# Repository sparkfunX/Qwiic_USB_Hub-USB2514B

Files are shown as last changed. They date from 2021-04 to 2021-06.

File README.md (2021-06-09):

SparkFun Qwiic USB Hub - USB2514B
========================================

SparkX USB Hub - USB2514B (Qwiic) (https://www.sparkfun.com/products/18014)

[*SparkX USB Hub - USB2514B (Qwiic) (SPX-18014)*](https://www.sparkfun.com/products/18014)

There are times when you have multiple USB devices in your prototype or device and you just want to plug in one cable. You need a built in USB hub! 

The [Qwiic USB Hub](https://www.sparkfun.com/products/18014) is a simple breakout board for the USB2514B USB hub IC. What gives it extra flair is the ability to configure the device over I2C. Out of the box, the board will appear as a standard USB 2.0 Hub; no configuration necessary. Closing the I2C jumper will put the device into configuration mode. We've got an Arduino Library to help you set the various parameters of the hub including VID/PID, downstream max current, even language ID and product names. 

Note: Once the configuration bytes are set and the USB2514B is told to 'attach' it will enumerate as a HUB and the configuration cannot be changed until the IC is reset. 

The USB2514 is a 4-port 2.0 USB hub. Who cares about USB 2.0 these days? The vast majority of projects we work on have a simple USB-to-Serial IC on it that do not require gigabit datarates. The USB251xB is a simple hub IC allowing multiple USB things to live under one USB connection; this is especially useful when prototyping a new product where you want the user to plug in just one cable.

SparkFun labored with love to create this code. Feel like supporting open source hardware? 
Buy a [board](https://www.sparkfun.com/products/18014) from SparkFun!

Repository Contents
-------------------

* **/hardware** - Eagle files
* **/documents** - Datasheets and other source documents

Documentation
--------------

* **[Arduino Library](https://github.com/sparkfun/SparkFun_USB251x_Arduino_Library)** - Main repository (including hardware files)
* **[Installing an Arduino Library Guide](https://learn.sparkfun.com/tutorials/installing-an-arduino-library)** - Basic information on how to install an Arduino library.

Products that use this Repository
--------------

* [SPX-18014](https://www.sparkfun.com/products/18014)

License Information
-------------------

This product is _**open source**_! 

Please review the LICENSE.md file for license information. 

If you have any questions or concerns on licensing, please contact technical support on our [SparkFun forums](https://forum.sparkfun.com/viewforum.php?f=152).

Distributed as-is; no warranty is given.

- Your friends at SparkFun.

_<COLLABORATION CREDIT>_

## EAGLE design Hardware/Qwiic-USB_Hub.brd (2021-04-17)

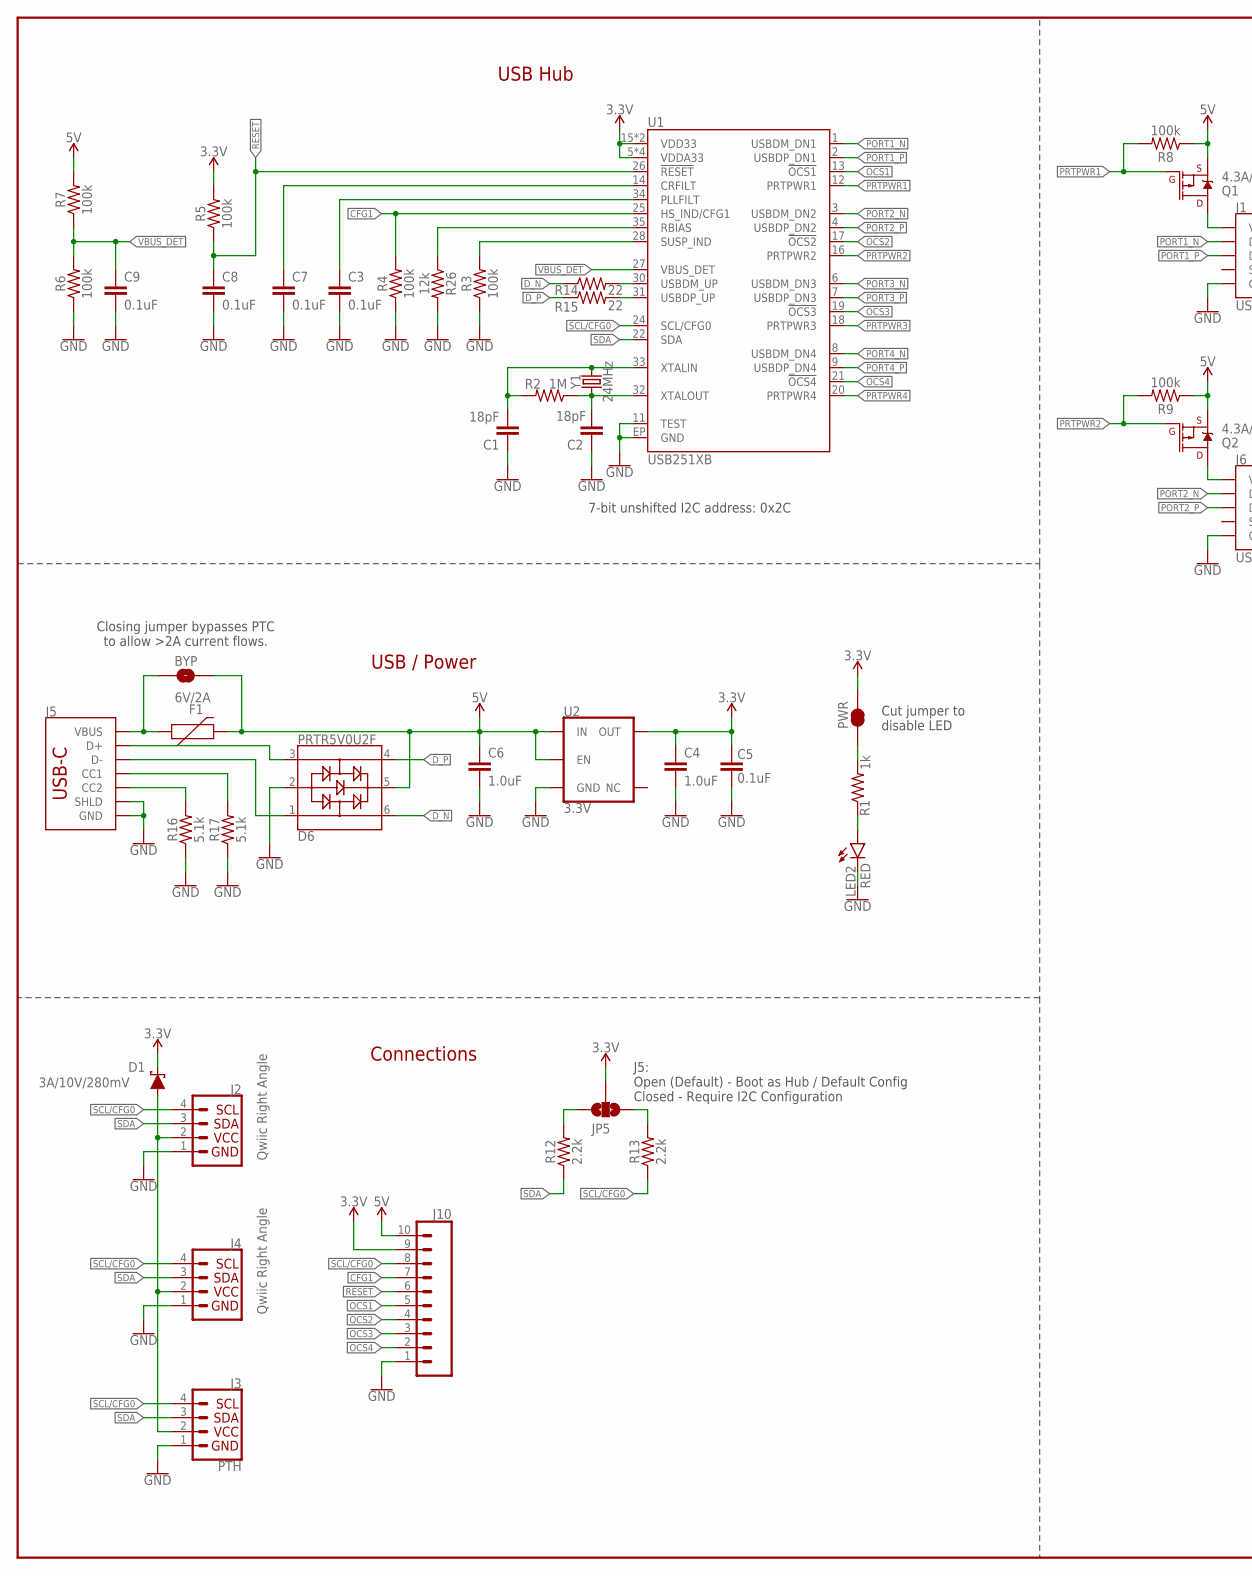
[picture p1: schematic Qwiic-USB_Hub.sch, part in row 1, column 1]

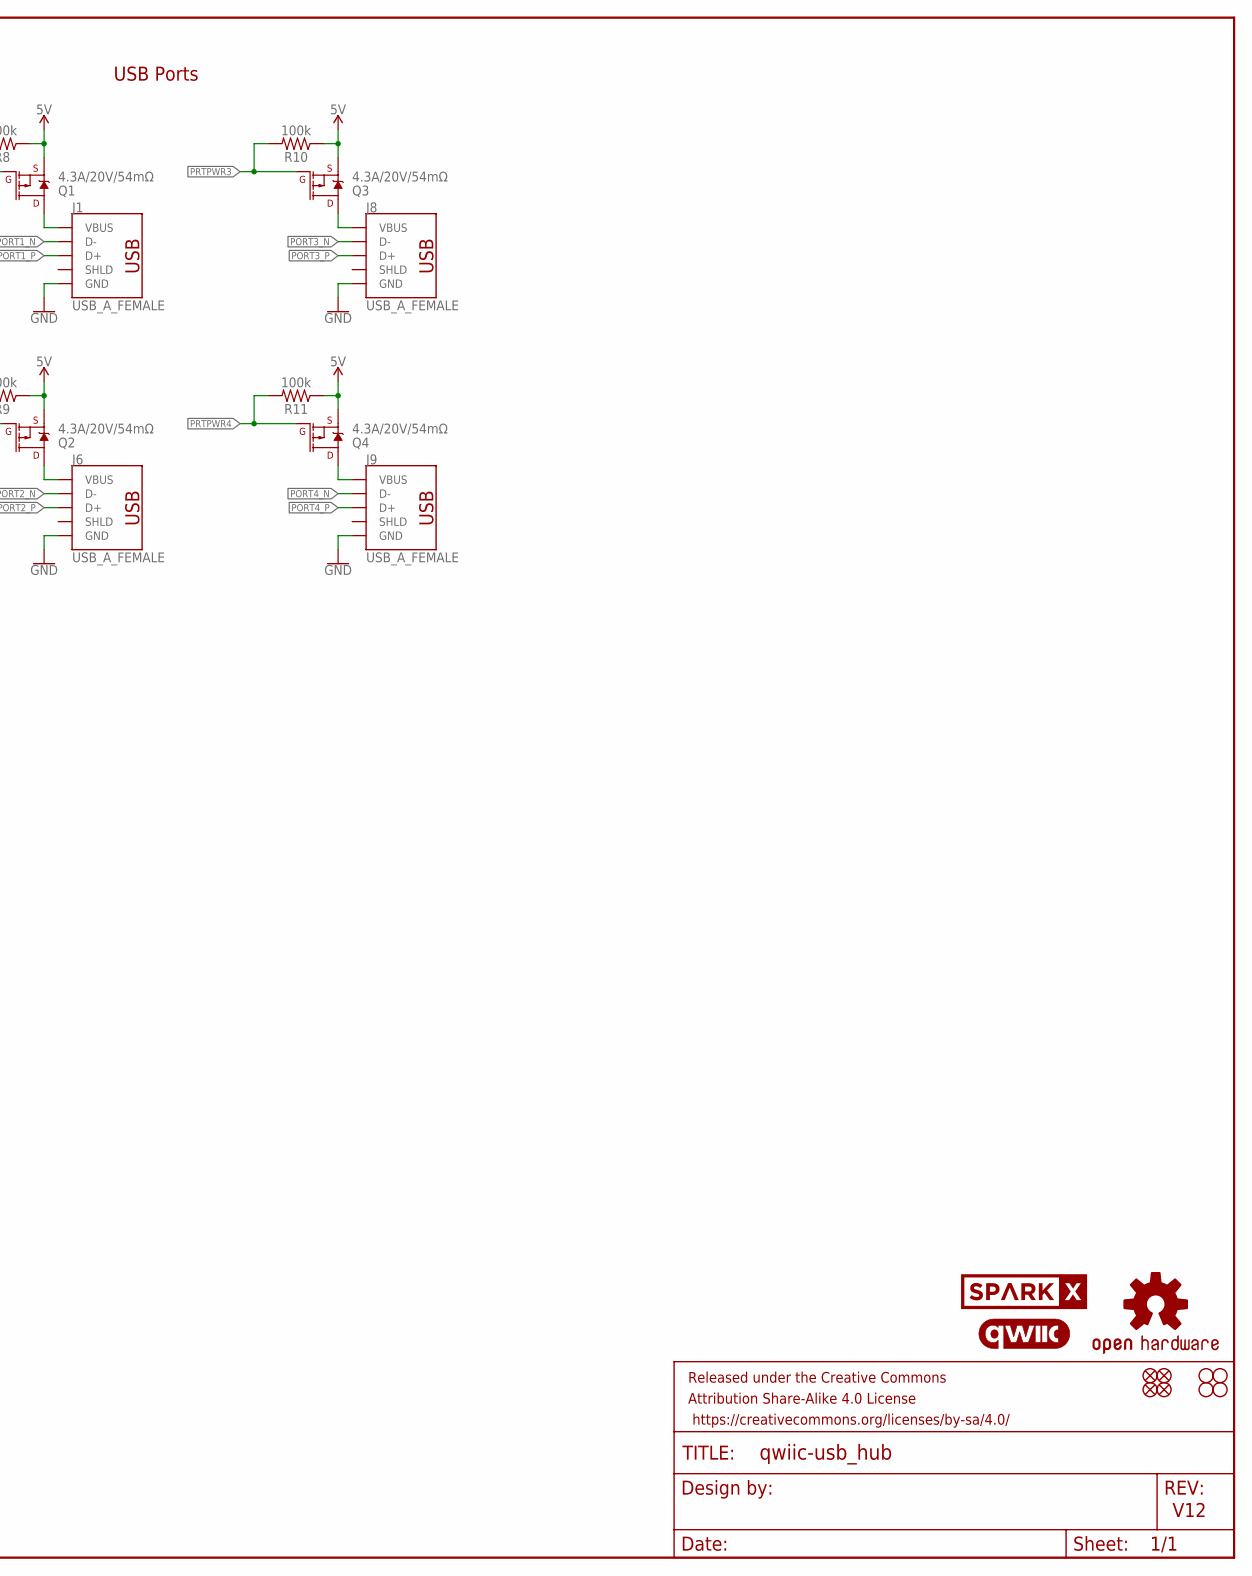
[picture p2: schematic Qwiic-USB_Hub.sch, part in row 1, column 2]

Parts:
BYP: JUMPER-SMT_2_NO_SILK; SMT-JUMPER_2_NO_SILK
C1, C2: 18pF; 0603
C3, C5, C7, C8, C9: 0.1uF; 0603
C4, C6: 1.0uF; 0603
D1: 3A/10V/280mV; SOD-323
D6: PRTR5V0U2F; SOT886
F1: 6V/2A; 1210
FRAME2: FRAME-LEDGER; CREATIVE_COMMONS
J1, J6, J8, J9: USB_A_FEMALE; USB-A-S-NOSILK-FEMALE
J2, J4: Qwiic Right Angle; JST04_1MM_RA
J3: PTH; 1X04_NO_SILK
J5: USB_C_2-LAYER_PADS; USB-C-16P-2LAYER-PADS
J10: CONN_10NO_SILK_PTH_FEMALE; 1X10_NO_SILK
JP5: JUMPER-SMT_3_NO_SILK; SMT-JUMPER_3_NO_SILK
JP21, JP61, JP71, JP81: FIDUCIALUFIDUCIAL; MICRO-FIDUCIAL
JP31, JP41, JP91, JP101: STAND-OFF
LED2: RED; LED-0603
LOGO1: OSHW-LOGOMINI; OSHW-LOGO-MINI
LOGO2: QWIIC_LOGO_CONNECTOR; QWIIC_5.5MM
PWR: JUMPER-SMT_2_NC_TRACE_SILK; SMT-JUMPER_2_NC_TRACE_SILK
Q1, Q2, Q3, Q4: 4.3A/20V/54mΩ; SOT23-3
R1: 1k; 0603
R2: 1M; 0603
R3, R4, R5, R6, R7, R8, R9, R10, R11: 100k; 0603
R12, R13: 2.2k; 0603
R14, R15: 22; 0603
R16, R17: 5.1k; 0603
R26: 12k; 0603
U1: USB251XB; QFN-36
U2: 3.3V; SOT23-5
U$5: SPARKX-LOGO4; SPARKX-MEDIUM
Y1: 24MHz; CRYSTAL-SMD-2.0X1.6MM

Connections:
3.3V: C4.1, C5.2, D1.C, J10.9, JP5.2, PWR.2, R5.2, U1.5 (VDDA33), U1.10 (VDDA33), U1.15 (VDD33), U1.23 (VDD33), U1.29 (VDDA33), U1.36 (VDDA33), U2.5 (OUT)
5V: BYP.2, C6.1, D6.5, F1.2, J10.10, Q1.2 (S), Q2.2 (S), Q3.2 (S), Q4.2 (S), R7.2, R8.1, R9.1, R10.1, R11.1, U2.1 (IN), U2.3 (EN)
!OCS1: J10.5, U1.13 (!OCS1)
!OCS2: J10.4, U1.17 (!OCS2)
!OCS3: J10.3, U1.19 (!OCS3)
!OCS4: J10.2, U1.21 (!OCS4)
!RESET: C8.1, J10.6, R5.1, U1.26 (!RESET)
CC1: J5.A5 (CC1), R17.2
CC2: J5.B5 (CC2), R16.2
CFG1: J10.7, R4.2, U1.25 (HS_IND/CFG1)
D_N: D6.6, R14.1
D_P: D6.4, R15.1
GND: C1.1, C2.1, C3.2, C4.2, C5.1, C6.2, C7.2, C8.2, C9.2, D6.2, J1.GND, J2.1, J3.1 (GND), J4.1, J5.GND, J5.GND2 (GND), J5.SHLD1 (SHLD), J5.SHLD2 (SHLD), J5.SHLD3 (SHLD), J5.SHLD4 (SHLD), J6.GND, J8.GND, J9.GND, J10.1, LED2.C, R3.1, R4.1, R6.1, R16.1, R17.1, R26.2, U1.11 (TEST), U1.EP (GND), U2.2 (GND)
unnamed: J1.VBUS, Q1.3 (D)
unnamed: J6.VBUS, Q2.3 (D)
unnamed: J8.VBUS, Q3.3 (D)
unnamed: J9.VBUS, Q4.3 (D)
unnamed: R26.1, U1.35 (RBIAS)
unnamed: C1.2, R2.2, U1.33 (XTALIN), Y1.3 (2)
unnamed: BYP.1, F1.1, J5.VBUS1 (VBUS), J5.VBUS2 (VBUS)
unnamed: C2.2, R2.1, U1.32 (XTALOUT), Y1.1
unnamed: JP5.1, R13.2
unnamed: LED2.A, R1.1
unnamed: R3.2, U1.28 (SUSP_IND)
unnamed: C3.1, U1.34 (PLLFILT)
unnamed: C7.1, U1.14 (CRFILT)
unnamed: JP5.3, R12.2
unnamed: R14.2, U1.30 (USBDM_UP)
unnamed: PWR.1, R1.2
unnamed: R15.2, U1.31 (USBDP_UP)
unnamed: D1.A, J2.2, J3.2 (VCC), J4.2
PORT1_N: J1.D-, U1.1 (USBDM_DN1)
PORT1_P: J1.D+, U1.2 (USBDP_DN1)
PORT2_N: J6.D-, U1.3 (USBDM_DN2)
PORT2_P: J6.D+, U1.4 (USBDP_DN2)
PORT3_N: J8.D-, U1.6 (USBDM_DN3)
PORT3_P: J8.D+, U1.7 (USBDP_DN3)
PORT4_N: J9.D-, U1.8 (USBDM_DN4)
PORT4_P: J9.D+, U1.9 (USBDP_DN4)
PRTPWR1: Q1.1 (G), R8.2, U1.12 (PRTPWR1)
PRTPWR2: Q2.1 (G), R9.2, U1.16 (PRTPWR2)
PRTPWR3: Q3.1 (G), R10.2, U1.18 (PRTPWR3)
PRTPWR4: Q4.1 (G), R11.2, U1.20 (PRTPWR4)
SCL/CFG0: J2.4, J3.4 (SCL), J4.4, J10.8, R13.1, U1.24 (SCL/CFG0)
SDA: J2.3, J3.3 (SDA), J4.3, R12.1, U1.22 (SDA)
UNP_D+: D6.3, J5.A6 (D+), J5.B6 (D+)
UNP_D-: D6.1, J5.A7 (D-), J5.B7 (D-)
VBUS_DET: C9.1, R6.2, R7.1, U1.27 (VBUS_DET)

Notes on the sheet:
V12
7-bit unshifted I2C address: 0x2C
Cut jumper to disable LED
USB Hub
USB / Power
USB Ports
Connections
Closing jumper bypasses PTC to allow >2A current flows.
J5: Open (Default) - Boot as Hub / Default Config Closed - Require I2C Configuration

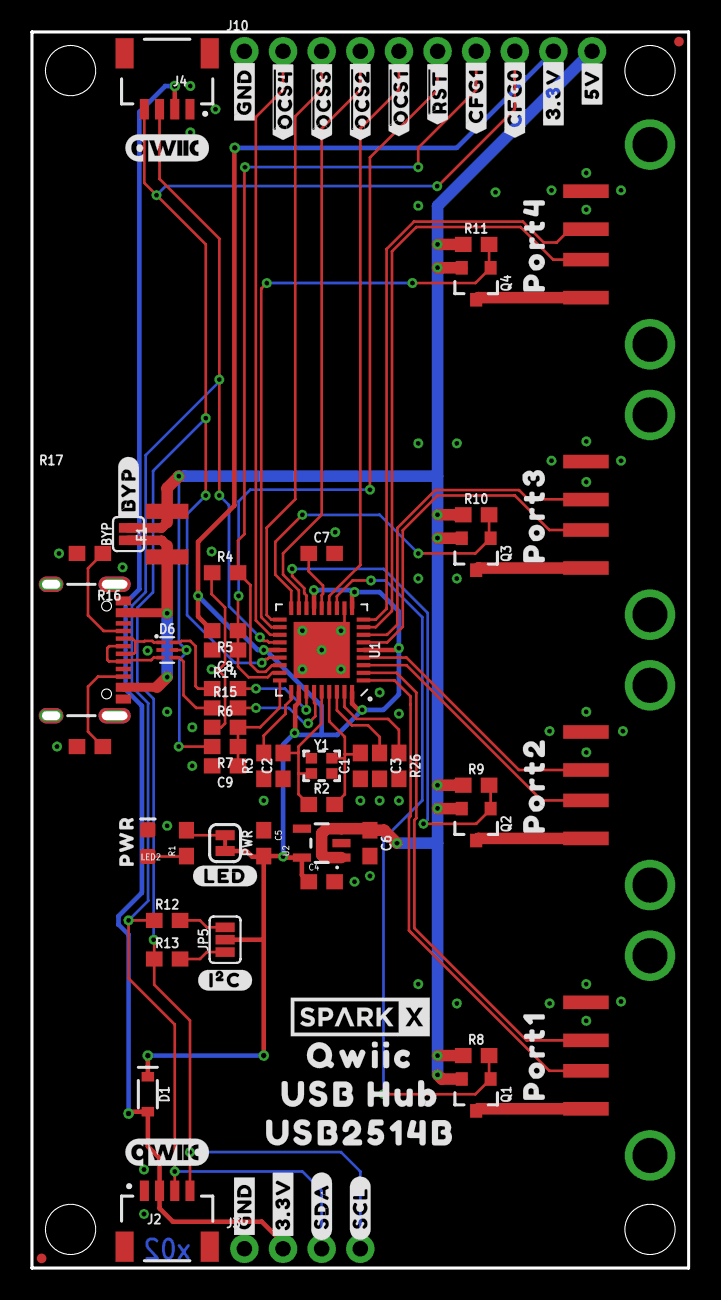
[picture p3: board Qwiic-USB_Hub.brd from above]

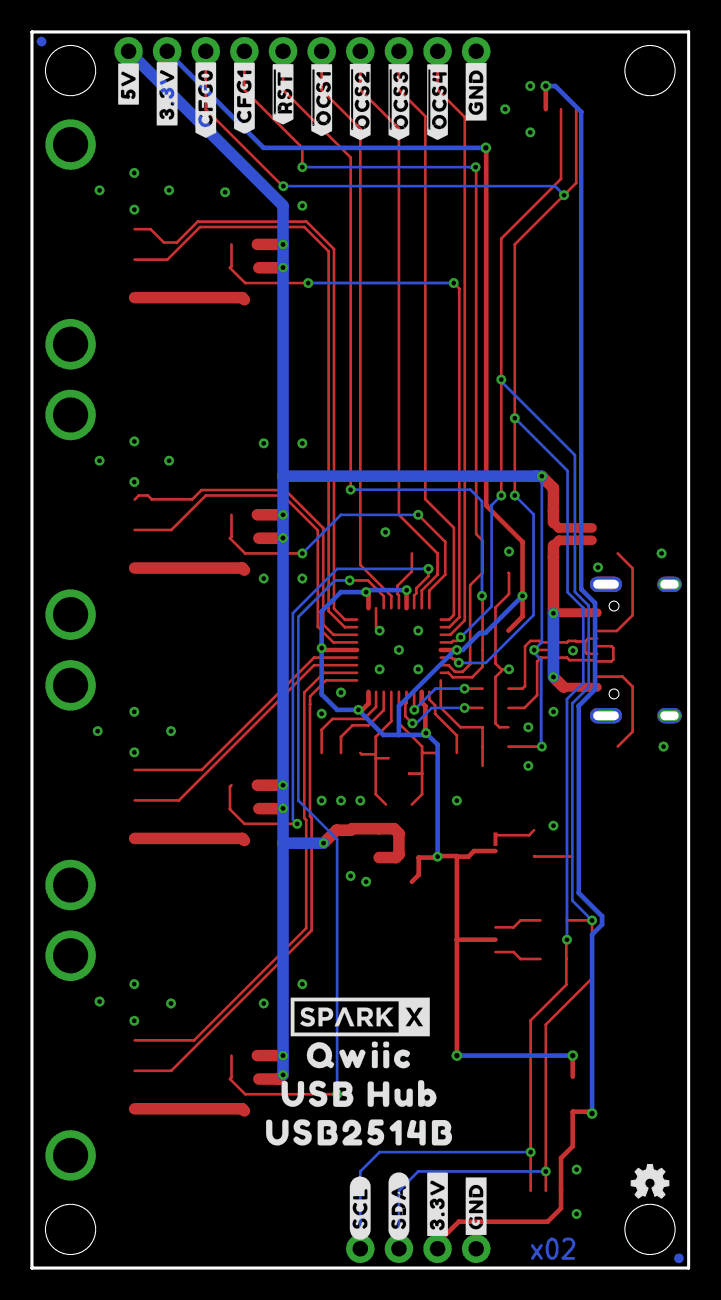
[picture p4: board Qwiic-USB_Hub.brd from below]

Board: 2 copper layers, 43.2 x 81.3 mm, 106 parts (21 on the bottom side), 48 nets.

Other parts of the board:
U$1: PORT40
U$2: PORT31
U$3: PORT22
U$4: PORT13
U$6, U$34: #3#3V#0
U$7, U$35: #SDA#0
U$8, U$36: #SCL#0
U$9, U$33: #GND#0
U$10: #I�C#1
U$11, U$16: #GND#5
U$12: PWR0
U$13, U$31: ##RST##4
U$14, U$32: #3#3V#6
U$15, U$37: #5V#7
U$17, U$30: ##OCS1##3
U$18, U$43: ##OCS2##2
U$19, U$44: ##OCS3##1
U$20, U$45: ##OCS4##0
U$21: #BYP#0
U$22, U$39: QWIIC2
U$23: #LED#0
U$24, U$29: #CFG0#1
U$25, U$28: #CFG1#0
U$26, U$41: USB2514B0
U$27, U$40: USB_HUB1
U$38: SPARKX-LOGO4; SPARKX-MEDIUM
U$42: QWIIC_5.5MM

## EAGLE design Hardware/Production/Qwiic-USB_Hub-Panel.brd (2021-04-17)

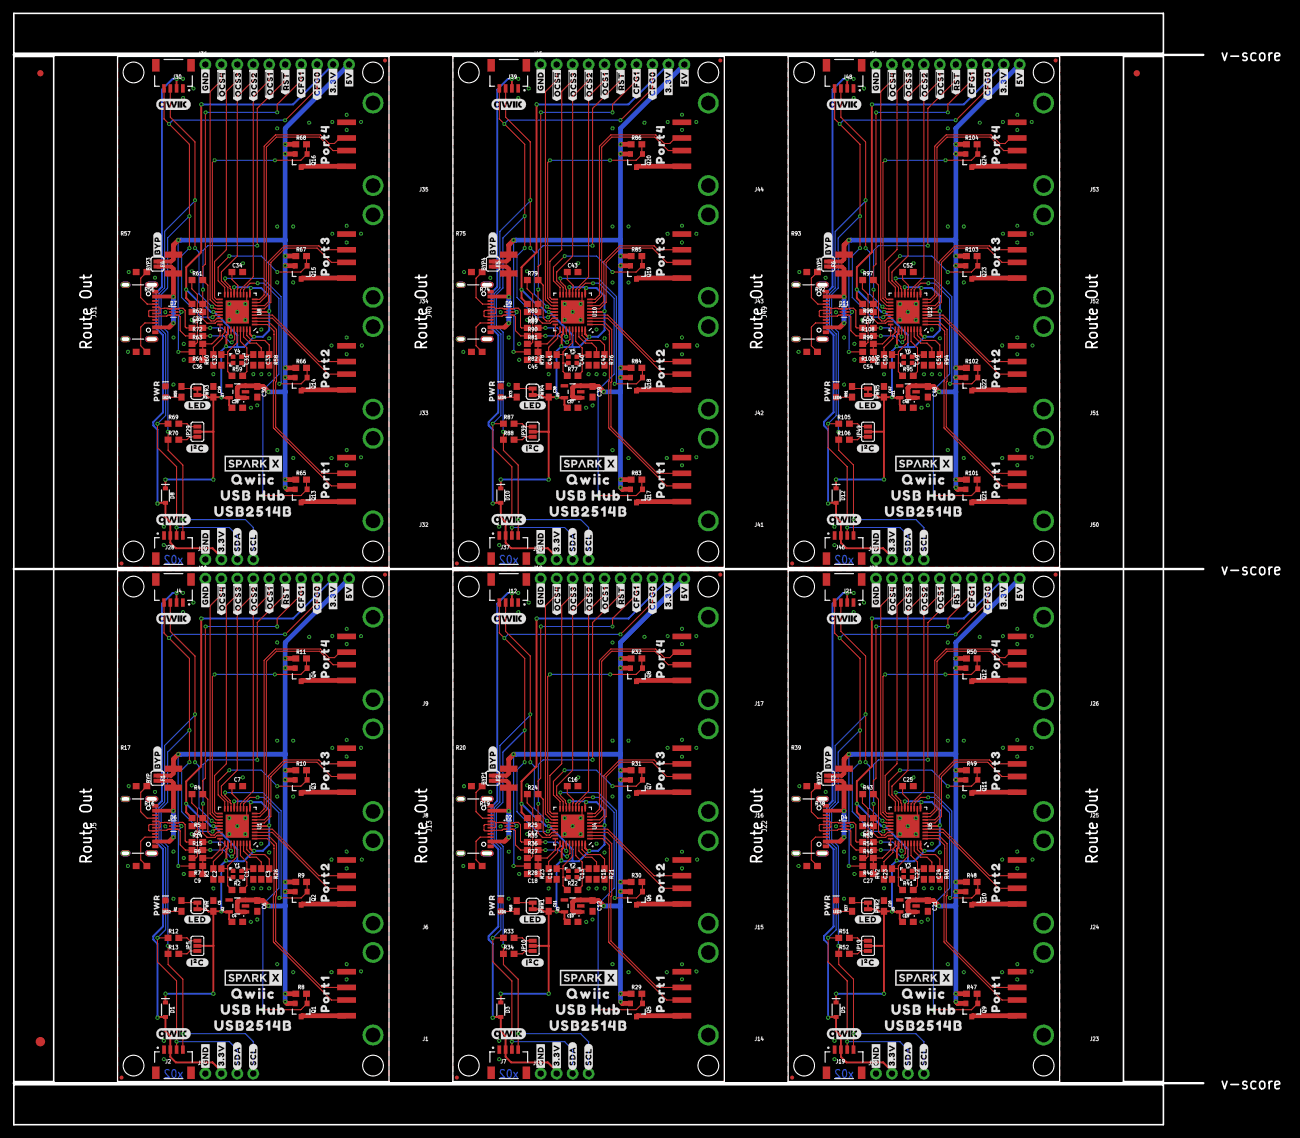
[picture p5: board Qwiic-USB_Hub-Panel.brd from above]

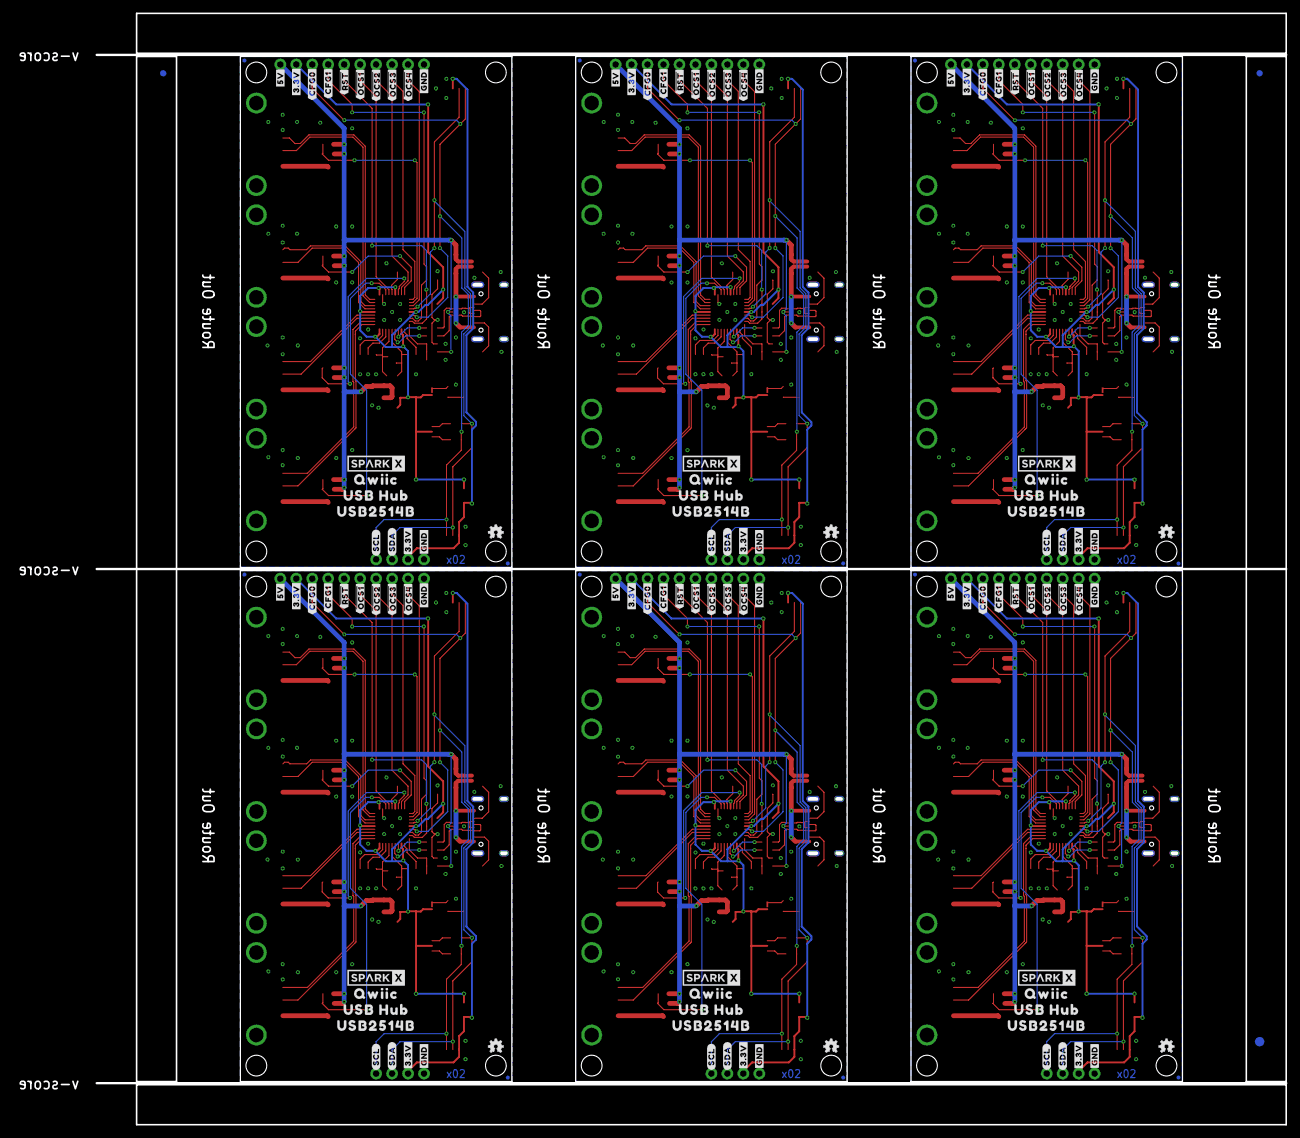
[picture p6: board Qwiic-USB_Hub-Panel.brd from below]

Board: 2 copper layers, 189.2 x 176.8 mm, 636 parts (129 on the bottom side), 288 nets.

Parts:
BYP, BYP1, BYP2, BYP3, BYP4, BYP5: JUMPER-SMT_2_NO_SILK; SMT-JUMPER_2_NO_SILK
C1, C2, C13, C14, C22, C23, C31, C32, C40, C41, C49, C50: 18pF; 0603
C3, C5, C7, C8, C9, C11, C15, C16, C17, C18, C20, C24, C25, C26, C27, C29, C33, C34, C35, C36, C38, C42, C43, C44, C45, C47, C51, C52, C53, C54: 0.1uF; 0603
C4, C6, C10, C12, C19, C21, C28, C30, C37, C39, C46, C48: 1.0uF; 0603
D1, D3, D5, D8, D10, D12: 3A/10V/280mV; SOD-323
D2, D4, D6, D7, D9, D11: PRTR5V0U2F; SOT886
E$1, E$2, E$3, E$4: FIDUCIAL-1X2
E$5, E$6: FIDUCIAL-1.5X3
F1, F2, F3, F4, F5, F6: 6V/2A; 1210
J1, J6, J8, J9, J14, J15, J16, J17, J23, J24, J25, J26, J32, J33, J34, J35, J41, J42, J43, J44, J50, J51, J52, J53: USB_A_FEMALE; USB-A-S-NOSILK-FEMALE
J2, J4, J7, J12, J19, J21, J28, J30, J37, J39, J46, J48: Qwiic Right Angle; JST04_1MM_RA
J3, J11, J20, J29, J38, J47: PTH; 1X04_NO_SILK
J5, J13, J22, J31, J40, J49: USB-C-16P-2LAYER-PADS
J10, J18, J27, J36, J45, J54: 1X10_NO_SILK
JP1, JP2, JP8, JP9, JP11, JP12, JP17, JP18, JP20, JP22, JP27, JP28, JP30, JP31, JP32, JP37, JP38, JP40, JP41, JP42, JP47, JP48, JP91, JP101: STAND-OFF
JP3, JP4, JP6, JP7, JP13, JP14, JP15, JP16, JP21, JP23, JP24, JP25, JP26, JP33, JP34, JP35, JP36, JP43, JP44, JP45, JP46, JP61, JP71, JP81: FIDUCIALUFIDUCIAL; MICRO-FIDUCIAL
JP5, JP10, JP19, JP29, JP39, JP49: SMT-JUMPER_3_NO_SILK
LED1, LED2, LED3, LED4, LED5, LED6: RED; LED-0603
LOGO1, LOGO3, LOGO5, LOGO7, LOGO9, LOGO11: OSHW-LOGOMINI; OSHW-LOGO-MINI
LOGO2, LOGO4, LOGO6, LOGO8, LOGO10, LOGO12: QWIIC_LOGO_CONNECTOR; QWIIC_5.5MM
PWR, PWR1, PWR2, PWR3, PWR4, PWR5: SMT-JUMPER_2_NC_TRACE_SILK
Q1, Q2, Q3, Q4, Q5, Q6, Q7, Q8, Q9, Q10, Q11, Q12, Q13, Q14, Q15, Q16, Q17, Q18, Q19, Q20, Q21, Q22, Q23, Q24: 4.3A/20V/54mΩ; SOT23-3
R1, R18, R37, R55, R73, R91: 1k; 0603
R2, R22, R41, R59, R77, R95: 1M; 0603
R3, R4, R5, R6, R7, R8, R9, R10, R11, R23, R24, R25, R27, R28, R29, R30, R31, R32, R42, R43, R44, R45, R46, R47, R48, R49, R50, R60, R61, R62, R63, R64, R65, R66, R67, R68, R78, R79, R80, R81, R82, R83, R84, R85, R86, R96, R97, R98, R99, R100, R101, R102, R103, R104: 100k; 0603
R12, R13, R33, R34, R51, R52, R69, R70, R87, R88, R105, R106: 2.2k; 0603
R14, R15, R35, R36, R53, R54, R71, R72, R89, R90, R107, R108: 22; 0603
R16, R17, R19, R20, R38, R39, R56, R57, R74, R75, R92, R93: 5.1k; 0603
R21, R26, R40, R58, R76, R94: 12k; 0603
U1, U4, U6, U8, U10, U12: USB251XB; QFN-36
U2, U3, U5, U7, U9, U11: 3.3V; SOT23-5
U$1, U$46, U$91, U$136, U$181, U$226: PORT40
U$2, U$47, U$92, U$137, U$182, U$227: PORT31
U$3, U$48, U$93, U$138, U$183, U$228: PORT22
U$4, U$49, U$94, U$139, U$184, U$229: PORT13
U$5, U$38, U$50, U$74, U$95, U$119, U$140, U$164, U$185, U$209, U$230, U$254: SPARKX-LOGO4; SPARKX-MEDIUM
U$6, U$34, U$51, U$54, U$96, U$99, U$141, U$144, U$186, U$189, U$231, U$234: #3#3V#0
U$7, U$35, U$52, U$55, U$97, U$100, U$142, U$145, U$187, U$190, U$232, U$235: #SDA#0
U$8, U$36, U$53, U$56, U$98, U$101, U$143, U$146, U$188, U$191, U$233, U$236: #SCL#0
U$9, U$33, U$57, U$58, U$102, U$103, U$147, U$148, U$192, U$193, U$237, U$238: #GND#0
U$10, U$59, U$104, U$149, U$194, U$239: #I�C#1
U$11, U$16, U$64, U$70, U$109, U$115, U$154, U$160, U$199, U$205, U$244, U$250: #GND#5
U$12, U$60, U$105, U$150, U$195, U$240: PWR0
U$13, U$31, U$61, U$71, U$106, U$116, U$151, U$161, U$196, U$206, U$241, U$251: ##RST##4
U$14, U$32, U$62, U$72, U$107, U$117, U$152, U$162, U$197, U$207, U$242, U$252: #3#3V#6
U$15, U$37, U$63, U$73, U$108, U$118, U$153, U$163, U$198, U$208, U$243, U$253: #5V#7
U$17, U$30, U$79, U$87, U$124, U$132, U$169, U$177, U$214, U$222, U$259, U$267: ##OCS1##3
U$18, U$43, U$80, U$88, U$125, U$133, U$170, U$178, U$215, U$223, U$260, U$268: ##OCS2##2
U$19, U$44, U$81, U$89, U$126, U$134, U$171, U$179, U$216, U$224, U$261, U$269: ##OCS3##1
U$20, U$45, U$82, U$90, U$127, U$135, U$172, U$180, U$217, U$225, U$262, U$270: ##OCS4##0
U$21, U$65, U$110, U$155, U$200, U$245: #BYP#0
U$22, U$39, U$67, U$75, U$112, U$120, U$157, U$165, U$202, U$210, U$247, U$255: QWIIC2
U$23, U$69, U$114, U$159, U$204, U$249: #LED#0
U$24, U$29, U$83, U$86, U$128, U$131, U$173, U$176, U$218, U$221, U$263, U$266: #CFG0#1
U$25, U$28, U$84, U$85, U$129, U$130, U$174, U$175, U$219, U$220, U$264, U$265: #CFG1#0
U$26, U$41, U$66, U$77, U$111, U$122, U$156, U$167, U$201, U$212, U$246, U$257: USB2514B0
U$27, U$40, U$68, U$76, U$113, U$121, U$158, U$166, U$203, U$211, U$248, U$256: USB_HUB1
U$42, U$78, U$123, U$168, U$213, U$258: QWIIC_5.5MM
Y1, Y2, Y3, Y4, Y5, Y6: 24MHz; CRYSTAL-SMD-2.0X1.6MM

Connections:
3.3V: C4.1, C5.2, D1.C, J10.9, JP5.2, PWR.2, R5.2, U1.5, U1.10, U1.15, U1.23, U1.29, U1.36, U2.5
3.3V1: C10.1, C11.2, D3.C, J18.9, JP10.2, PWR1.2, R25.2, U3.5, U4.5, U4.10, U4.15, U4.23, U4.29, U4.36
3.3V2: C19.1, C20.2, D5.C, J27.9, JP19.2, PWR2.2, R44.2, U5.5, U6.5, U6.10, U6.15, U6.23, U6.29, U6.36
3.3V3: C28.1, C29.2, D8.C, J36.9, JP29.2, PWR3.2, R62.2, U7.5, U8.5, U8.10, U8.15, U8.23, U8.29, U8.36
3.3V4: C37.1, C38.2, D10.C, J45.9, JP39.2, PWR4.2, R80.2, U9.5, U10.5, U10.10, U10.15, U10.23, U10.29, U10.36
3.3V5: C46.1, C47.2, D12.C, J54.9, JP49.2, PWR5.2, R98.2, U11.5, U12.5, U12.10, U12.15, U12.23, U12.29, U12.36
5V: BYP.2, C6.1, D6.5, F1.2, J10.10, Q1.2, Q2.2, Q3.2, Q4.2, R7.2, R8.1, R9.1, R10.1, R11.1, U2.1, U2.3
5V1: BYP1.2, C12.1, D2.5, F2.2, J18.10, Q5.2, Q6.2, Q7.2, Q8.2, R28.2, R29.1, R30.1, R31.1, R32.1, U3.1, U3.3
5V2: BYP2.2, C21.1, D4.5, F3.2, J27.10, Q9.2, Q10.2, Q11.2, Q12.2, R46.2, R47.1, R48.1, R49.1, R50.1, U5.1, U5.3
5V3: BYP3.2, C30.1, D7.5, F4.2, J36.10, Q13.2, Q14.2, Q15.2, Q16.2, R64.2, R65.1, R66.1, R67.1, R68.1, U7.1, U7.3
5V4: BYP4.2, C39.1, D9.5, F5.2, J45.10, Q17.2, Q18.2, Q19.2, Q20.2, R82.2, R83.1, R84.1, R85.1, R86.1, U9.1, U9.3
5V5: BYP5.2, C48.1, D11.5, F6.2, J54.10, Q21.2, Q22.2, Q23.2, Q24.2, R100.2, R101.1, R102.1, R103.1, R104.1, U11.1, U11.3
!OCS1: J10.5, U1.13
!OCS2: J10.4, U1.17
!OCS3: J10.3, U1.19
!OCS4: J10.2, U1.21
!OCS5: J18.5, U4.13
!OCS6: J18.4, U4.17
!OCS7: J18.3, U4.19
!OCS8: J18.2, U4.21
!OCS9: J27.5, U6.13
!OCS10: J27.4, U6.17
!OCS11: J27.3, U6.19
!OCS12: J27.2, U6.21
!OCS13: J36.5, U8.13
!OCS14: J36.4, U8.17
!OCS15: J36.3, U8.19
!OCS16: J36.2, U8.21
!OCS17: J45.5, U10.13
!OCS18: J45.4, U10.17
!OCS19: J45.3, U10.19
!OCS20: J45.2, U10.21
!OCS21: J54.5, U12.13
!OCS22: J54.4, U12.17
!OCS23: J54.3, U12.19
!OCS24: J54.2, U12.21
!RESET: C8.1, J10.6, R5.1, U1.26
!RESET1: C17.1, J18.6, R25.1, U4.26
!RESET2: C26.1, J27.6, R44.1, U6.26
!RESET3: C35.1, J36.6, R62.1, U8.26
!RESET4: C44.1, J45.6, R80.1, U10.26
!RESET5: C53.1, J54.6, R98.1, U12.26
CC1: J5.A5, R17.2
CC2: J5.B5, R16.2
CC3: J13.A5, R20.2
CC4: J13.B5, R19.2
CC5: J22.A5, R39.2
CC6: J22.B5, R38.2
CC7: J31.A5, R57.2
CC8: J31.B5, R56.2
CC9: J40.A5, R75.2
CC10: J40.B5, R74.2
CC11: J49.A5, R93.2
CC12: J49.B5, R92.2
CFG1: J10.7, R4.2, U1.25
CFG2: J18.7, R24.2, U4.25
CFG3: J27.7, R43.2, U6.25
CFG4: J36.7, R61.2, U8.25
CFG5: J45.7, R79.2, U10.25
CFG6: J54.7, R97.2, U12.25
D_N: D6.6, R14.1
D_N1: D2.6, R35.1
D_N2: D4.6, R53.1
D_N3: D7.6, R71.1
D_N4: D9.6, R89.1
D_N5: D11.6, R107.1
D_P: D6.4, R15.1
D_P1: D2.4, R36.1
D_P2: D4.4, R54.1
D_P3: D7.4, R72.1
D_P4: D9.4, R90.1
D_P5: D11.4, R108.1
GND: C1.1, C2.1, C3.2, C4.2, C5.1, C6.2, C7.2, C8.2, C9.2, D6.2, J1.GND, J2.1, J3.1, J4.1, J5.GND, J5.GND2, J5.SHLD1, J5.SHLD2, J5.SHLD3, J5.SHLD4, J6.GND, J8.GND, J9.GND, J10.1, LED2.C, R3.1, R4.1, R6.1, R16.1, R17.1, R26.2, U1.11, U1.EP, U2.2
GND1: C10.2, C11.1, C12.2, C13.1, C14.1, C15.2, C16.2, C17.2, C18.2, D2.2, J7.1, J11.1, J12.1, J13.GND, J13.GND2, J13.SHLD1, J13.SHLD2, J13.SHLD3, J13.SHLD4, J14.GND, J15.GND, J16.GND, J17.GND, J18.1, LED1.C, R19.1, R20.1, R21.2, R23.1, R24.1, R27.1, U3.2, U4.11, U4.EP
GND2: C19.2, C20.1, C21.2, C22.1, C23.1, C24.2, C25.2, C26.2, C27.2, D4.2, J19.1, J20.1, J21.1, J22.GND, J22.GND2, J22.SHLD1, J22.SHLD2, J22.SHLD3, J22.SHLD4, J23.GND, J24.GND, J25.GND, J26.GND, J27.1, LED3.C, R38.1, R39.1, R40.2, R42.1, R43.1, R45.1, U5.2, U6.11, U6.EP
GND3: C28.2, C29.1, C30.2, C31.1, C32.1, C33.2, C34.2, C35.2, C36.2, D7.2, J28.1, J29.1, J30.1, J31.GND, J31.GND2, J31.SHLD1, J31.SHLD2, J31.SHLD3, J31.SHLD4, J32.GND, J33.GND, J34.GND, J35.GND, J36.1, LED4.C, R56.1, R57.1, R58.2, R60.1, R61.1, R63.1, U7.2, U8.11, U8.EP
GND4: C37.2, C38.1, C39.2, C40.1, C41.1, C42.2, C43.2, C44.2, C45.2, D9.2, J37.1, J38.1, J39.1, J40.GND, J40.GND2, J40.SHLD1, J40.SHLD2, J40.SHLD3, J40.SHLD4, J41.GND, J42.GND, J43.GND, J44.GND, J45.1, LED5.C, R74.1, R75.1, R76.2, R78.1, R79.1, R81.1, U9.2, U10.11, U10.EP
GND5: C46.2, C47.1, C48.2, C49.1, C50.1, C51.2, C52.2, C53.2, C54.2, D11.2, J46.1, J47.1, J48.1, J49.GND, J49.GND2, J49.SHLD1, J49.SHLD2, J49.SHLD3, J49.SHLD4, J50.GND, J51.GND, J52.GND, J53.GND, J54.1, LED6.C, R92.1, R93.1, R94.2, R96.1, R97.1, R99.1, U11.2, U12.11, U12.EP
unnamed: J1.VBUS, Q1.3
unnamed: J6.VBUS, Q2.3
unnamed: J8.VBUS, Q3.3
unnamed: J9.VBUS, Q4.3
unnamed: R26.1, U1.35
unnamed: C1.2, R2.2, U1.33, Y1.3
unnamed: BYP.1, F1.1, J5.VBUS1, J5.VBUS2
unnamed: C2.2, R2.1, U1.32, Y1.1
unnamed: JP5.1, R13.2
unnamed: LED2.A, R1.1
unnamed: R3.2, U1.28
unnamed: LED1.A, R18.1
unnamed: C3.1, U1.34
unnamed: C7.1, U1.14
unnamed: JP5.3, R12.2
unnamed: R14.2, U1.30
unnamed: PWR.1, R1.2
unnamed: R15.2, U1.31
unnamed: PWR1.1, R18.2
unnamed: C13.2, R22.2, U4.33, Y2.3
unnamed: D1.A, J2.2, J3.2, J4.2
unnamed: C14.2, R22.1, U4.32, Y2.1
unnamed: R21.1, U4.35
unnamed: R23.2, U4.28
unnamed: C15.1, U4.34
unnamed: C16.1, U4.14
unnamed: J14.VBUS, Q5.3
unnamed: J15.VBUS, Q6.3
unnamed: J16.VBUS, Q7.3
unnamed: J17.VBUS, Q8.3
unnamed: BYP1.1, F2.1, J13.VBUS1, J13.VBUS2
unnamed: JP10.1, R34.2
unnamed: JP10.3, R33.2
unnamed: R35.2, U4.30
unnamed: R36.2, U4.31
unnamed: D3.A, J7.2, J11.2, J12.2
unnamed: LED3.A, R37.1
unnamed: PWR2.1, R37.2
unnamed: C22.2, R41.2, U6.33, Y3.3
unnamed: C23.2, R41.1, U6.32, Y3.1
unnamed: R40.1, U6.35
unnamed: R42.2, U6.28
unnamed: C24.1, U6.34
unnamed: C25.1, U6.14
unnamed: J23.VBUS, Q9.3
unnamed: J24.VBUS, Q10.3
unnamed: J25.VBUS, Q11.3
unnamed: J26.VBUS, Q12.3
unnamed: BYP2.1, F3.1, J22.VBUS1, J22.VBUS2
unnamed: JP19.1, R52.2
unnamed: JP19.3, R51.2
unnamed: R53.2, U6.30
unnamed: R54.2, U6.31
unnamed: D5.A, J19.2, J20.2, J21.2
unnamed: LED4.A, R55.1
unnamed: PWR3.1, R55.2
unnamed: C31.2, R59.2, U8.33, Y4.3
unnamed: C32.2, R59.1, U8.32, Y4.1
unnamed: R58.1, U8.35
unnamed: R60.2, U8.28
unnamed: C33.1, U8.34
unnamed: C34.1, U8.14
unnamed: J32.VBUS, Q13.3
unnamed: J33.VBUS, Q14.3
unnamed: J34.VBUS, Q15.3
unnamed: J35.VBUS, Q16.3
unnamed: BYP3.1, F4.1, J31.VBUS1, J31.VBUS2
unnamed: JP29.1, R70.2
unnamed: JP29.3, R69.2
unnamed: R71.2, U8.30
unnamed: R72.2, U8.31
unnamed: D8.A, J28.2, J29.2, J30.2
unnamed: LED5.A, R73.1
unnamed: PWR4.1, R73.2
unnamed: C40.2, R77.2, U10.33, Y5.3
unnamed: C41.2, R77.1, U10.32, Y5.1
unnamed: R76.1, U10.35
unnamed: R78.2, U10.28
unnamed: C42.1, U10.34
unnamed: C43.1, U10.14
unnamed: J41.VBUS, Q17.3
unnamed: J42.VBUS, Q18.3
unnamed: J43.VBUS, Q19.3
unnamed: J44.VBUS, Q20.3
unnamed: BYP4.1, F5.1, J40.VBUS1, J40.VBUS2
unnamed: JP39.1, R88.2
unnamed: JP39.3, R87.2
unnamed: R89.2, U10.30
unnamed: R90.2, U10.31
unnamed: D10.A, J37.2, J38.2, J39.2
unnamed: LED6.A, R91.1
unnamed: PWR5.1, R91.2
unnamed: C49.2, R95.2, U12.33, Y6.3
unnamed: C50.2, R95.1, U12.32, Y6.1
unnamed: R94.1, U12.35
unnamed: R96.2, U12.28
unnamed: C51.1, U12.34
unnamed: C52.1, U12.14
unnamed: J50.VBUS, Q21.3
unnamed: J51.VBUS, Q22.3
unnamed: J52.VBUS, Q23.3
unnamed: J53.VBUS, Q24.3
unnamed: BYP5.1, F6.1, J49.VBUS1, J49.VBUS2
unnamed: JP49.1, R106.2
unnamed: JP49.3, R105.2
unnamed: R107.2, U12.30
unnamed: R108.2, U12.31
unnamed: D12.A, J46.2, J47.2, J48.2
PORT1_N: J1.D-, U1.1
PORT1_N1: J14.D-, U4.1
PORT1_N2: J23.D-, U6.1
PORT1_N3: J32.D-, U8.1
PORT1_N4: J41.D-, U10.1
PORT1_N5: J50.D-, U12.1
PORT1_P: J1.D+, U1.2
PORT1_P1: J14.D+, U4.2
PORT1_P2: J23.D+, U6.2
PORT1_P3: J32.D+, U8.2
PORT1_P4: J41.D+, U10.2
PORT1_P5: J50.D+, U12.2
PORT2_N: J6.D-, U1.3
PORT2_N1: J15.D-, U4.3
PORT2_N2: J24.D-, U6.3
PORT2_N3: J33.D-, U8.3
PORT2_N4: J42.D-, U10.3
PORT2_N5: J51.D-, U12.3
PORT2_P: J6.D+, U1.4
PORT2_P1: J15.D+, U4.4
PORT2_P2: J24.D+, U6.4
PORT2_P3: J33.D+, U8.4
PORT2_P4: J42.D+, U10.4
PORT2_P5: J51.D+, U12.4
PORT3_N: J8.D-, U1.6
PORT3_N1: J16.D-, U4.6
PORT3_N2: J25.D-, U6.6
PORT3_N3: J34.D-, U8.6
PORT3_N4: J43.D-, U10.6
PORT3_N5: J52.D-, U12.6
PORT3_P: J8.D+, U1.7
PORT3_P1: J16.D+, U4.7
PORT3_P2: J25.D+, U6.7
PORT3_P3: J34.D+, U8.7
PORT3_P4: J43.D+, U10.7
PORT3_P5: J52.D+, U12.7
PORT4_N: J9.D-, U1.8
PORT4_N1: J17.D-, U4.8
PORT4_N2: J26.D-, U6.8
PORT4_N3: J35.D-, U8.8
PORT4_N4: J44.D-, U10.8
PORT4_N5: J53.D-, U12.8
PORT4_P: J9.D+, U1.9
PORT4_P1: J17.D+, U4.9
PORT4_P2: J26.D+, U6.9
PORT4_P3: J35.D+, U8.9
PORT4_P4: J44.D+, U10.9
PORT4_P5: J53.D+, U12.9
PRTPWR1: Q1.1, R8.2, U1.12
PRTPWR2: Q2.1, R9.2, U1.16
PRTPWR3: Q3.1, R10.2, U1.18
PRTPWR4: Q4.1, R11.2, U1.20
PRTPWR5: Q5.1, R29.2, U4.12
PRTPWR6: Q6.1, R30.2, U4.16
PRTPWR7: Q7.1, R31.2, U4.18
PRTPWR8: Q8.1, R32.2, U4.20
PRTPWR9: Q9.1, R47.2, U6.12
PRTPWR10: Q10.1, R48.2, U6.16
PRTPWR11: Q11.1, R49.2, U6.18
PRTPWR12: Q12.1, R50.2, U6.20
PRTPWR13: Q13.1, R65.2, U8.12
PRTPWR14: Q14.1, R66.2, U8.16
PRTPWR15: Q15.1, R67.2, U8.18
PRTPWR16: Q16.1, R68.2, U8.20
PRTPWR17: Q17.1, R83.2, U10.12
PRTPWR18: Q18.1, R84.2, U10.16
PRTPWR19: Q19.1, R85.2, U10.18
PRTPWR20: Q20.1, R86.2, U10.20
PRTPWR21: Q21.1, R101.2, U12.12
PRTPWR22: Q22.1, R102.2, U12.16
PRTPWR23: Q23.1, R103.2, U12.18
PRTPWR24: Q24.1, R104.2, U12.20
SCL/CFG0: J2.4, J3.4, J4.4, J10.8, R13.1, U1.24
SCL/CFG1: J7.4, J11.4, J12.4, J18.8, R34.1, U4.24
SCL/CFG2: J19.4, J20.4, J21.4, J27.8, R52.1, U6.24
SCL/CFG3: J28.4, J29.4, J30.4, J36.8, R70.1, U8.24
SCL/CFG4: J37.4, J38.4, J39.4, J45.8, R88.1, U10.24
SCL/CFG5: J46.4, J47.4, J48.4, J54.8, R106.1, U12.24
SDA: J2.3, J3.3, J4.3, R12.1, U1.22
SDA1: J7.3, J11.3, J12.3, R33.1, U4.22
SDA2: J19.3, J20.3, J21.3, R51.1, U6.22
SDA3: J28.3, J29.3, J30.3, R69.1, U8.22
SDA4: J37.3, J38.3, J39.3, R87.1, U10.22
SDA5: J46.3, J47.3, J48.3, R105.1, U12.22
UNP_D+: D6.3, J5.A6, J5.B6
UNP_D+1: D2.3, J13.A6, J13.B6
UNP_D+2: D4.3, J22.A6, J22.B6
UNP_D+3: D7.3, J31.A6, J31.B6
UNP_D+4: D9.3, J40.A6, J40.B6
UNP_D+5: D11.3, J49.A6, J49.B6
UNP_D-: D6.1, J5.A7, J5.B7
UNP_D-1: D2.1, J13.A7, J13.B7
UNP_D-2: D4.1, J22.A7, J22.B7
UNP_D-3: D7.1, J31.A7, J31.B7
UNP_D-4: D9.1, J40.A7, J40.B7
UNP_D-5: D11.1, J49.A7, J49.B7
VBUS_DET: C9.1, R6.2, R7.1, U1.27
VBUS_DET1: C18.1, R27.2, R28.1, U4.27
VBUS_DET2: C27.1, R45.2, R46.1, U6.27
VBUS_DET3: C36.1, R63.2, R64.1, U8.27
VBUS_DET4: C45.1, R81.2, R82.1, U10.27
VBUS_DET5: C54.1, R99.2, R100.1, U12.27

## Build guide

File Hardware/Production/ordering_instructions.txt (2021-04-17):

panel size, 183x177mm
PCB thickness, 1.6mm
number of layers, 2
soldermask color, Black
silkscreen color, White
oz copper, 1oz
finish, HASL lead free
stencils, none
pcs per panel, 6
min trace width, 0.1778mm / 0.0070in
min drill size, 0.3048mm / 0.0120in

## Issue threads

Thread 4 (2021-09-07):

QWIIC USB HUB USB2514B NOT SHUTTING OFF POWER TO PORTS

willpatton, 2021-09-07:
When programming the USB2514B PRTPWR pins, I noticed the 3.3V gate signal to the MOSFETS Q1-Q4 toggling as expected. However, the intent to turn off the P-CH MOSFET did not work (MOSFET is always on). I believe a 3.3V gate voltage from the USB2514B is not sufficient to turn off these particular P-CH MOSFETs. In fact, using a 3.3V chip to drive the gate of P-CH MOSFET for a 5V high-side switch is really a schematic error. The Microchip reference design for this board uses a 3.3V to 5.0V voltage translator chip (a gate driver) that properly drives the P-CH MOSFET gate signal to the 5.0V gate off state -- this board is missing that, so this design is defective because it cannot control PRTPWR to off for each of the USB-A connectors.

nseidle, 2021-09-07:
Thanks for reporting. Yep. I messed that up. We'll catch it on the next rev.

jvmatl, 2023-10-05:
Are there any plans/timelines for a next rev? Many (most?) low-priced hubs lack the hardware to fully disable ports under software control, but it's extremely useful for many automation tasks.

nseidle, 2023-10-05:
We don't have any plans at this time to carry the board after the current stock is exhausted. It's a very slow seller.

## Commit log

2021-02-04 Add ignore. Increase 3.3V width.
    [Qwiic-USB_Hub.brd, Qwiic-USB_Hub.sch]
2021-02-04 Add labels to bottom layer.
    [Qwiic-USB_Hub.brd]
2021-02-05 Fixing silk typo in OCS labels. Adding production panels.
    [Qwiic-USB_Hub-Panel.GBL, Qwiic-USB_Hub-Panel.GBO, Qwiic-USB_Hub-Panel.GBP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]
2021-02-22 Add Prod ID
    [Qwiic-USB_Hub-Panel.brd, Qwiic-USB_Hub.brd, Qwiic-USB_Hub.sch]
2021-04-17 Add connections to config pins.
    [Qwiic-USB_Hub.brd, Qwiic-USB_Hub.sch]
2021-04-17 Panel for x02
    [Qwiic-USB_Hub-Panel.brd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]
2021-04-17 Increase x02 panel size.
    [Qwiic-USB_Hub-Panel.GBL, Qwiic-USB_Hub-Panel.GBO, Qwiic-USB_Hub-Panel.GBS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]
2021-06-09 Add schematic and readme.

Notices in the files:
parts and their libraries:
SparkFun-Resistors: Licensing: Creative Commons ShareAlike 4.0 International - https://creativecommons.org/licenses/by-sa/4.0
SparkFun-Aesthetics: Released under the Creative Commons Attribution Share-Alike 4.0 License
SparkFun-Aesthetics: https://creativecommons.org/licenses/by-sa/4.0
